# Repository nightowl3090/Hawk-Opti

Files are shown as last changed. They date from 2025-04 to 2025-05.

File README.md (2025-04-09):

## Hawk - Open Source Xbox Live Communicator - But Cheaper!

This project is an open source replacement of the [Microsoft Xbox Live Communicator](https://xbox.fandom.com/wiki/Xbox_LIVE_Headset) utilizing modern components and custom open-source firmware. 

This is a redesign intended to reduce the cost of production and assembly by moving vias off-pad and moving all components to the front side of the PCB. These simple changes reduce production and assembly costs by as much as 50%. 

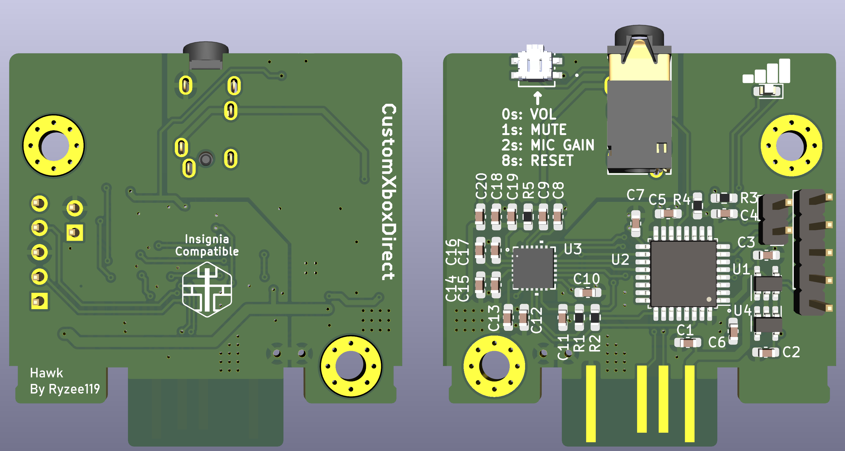
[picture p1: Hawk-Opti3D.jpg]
hawk!


It provides feature parity with the original communicator with the following differences:
* A 3.5mm TRRS jack is used to support more generic headsets. (Stereo headsets will output as mono.)
* The volume wheel is replaced with a button. Volume is indicated by LED brightness.

### Usage
* When installing Hawk into your controller, it must be installed in the slot closest to you.
* Press the button to increment the volume. Once maximum volume is reached, it will cycle back to zero.
* Hold the button for 1 second to mute and disable the microphone input (LED will flash at 1Hz).
* Hold the button 2 seconds to enter microphone gain adjustment mode (LED will flash at 4Hz).
* Volume and microphone gain adjustments will be saved internally. You can reset these to default by holding the button down for 8 seconds.

### Assembly
* **When ordering PCB thickness should be 1.2mm!**
* See [Kitspace](https://master.staging.kitspace.dev/Ryzee119/hawk) for BOM, PCB ordering and assembly information.
* See [KiCanvas](https://kicanvas.org/?github=https%3A%2F%2Fgithub.com%2FRyzee119%2Fhawk%2Ftree%2Fmaster%2Fhardware) for schematic view.
* See [Tracespace](https://tracespace.io/view/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) for Gerber view.

### Compilation
* Download and install [Visual Studio Code](https://code.visualstudio.com/).
* Install the [PlatformIO IDE](https://platformio.org/platformio-ide) plugin.
* In Visual Studio Code File > Open Folder... > hawk
* Hit build on the Platform IO toolbar (✓).

### Programming
* [Compile](https://github.com/Ryzee119/hawk?tab=readme-ov-file#compilation) or [Download](https://github.com/Ryzee119/hawk/releases) the pre-built firmware image.
* USB DFU. Connect an xbox controller to your PC, then hold the Hawk button down while inserting it into the controller to enter DFU mode. Your PC should detect this. you can then program with [STM32Cubeprogrammer](https://www.st.com/en/development-tools/stm32cubeprog.html)
* ST-Link interface (5 pin header available on PCB)

### FAQ
* What is the pinout of the headphone jack?
  * Hawk's headphone jack is wired as per [CTIA standard TRRS](https://upload.wikimedia.org/wikipedia/commons/e/ee/3.5mm_TRRS_phone_connector_with_CTIA_standard.png). There is another less common standard called OMTP. This will not work but adapters are available.
* It doesn't fit in my controller slot.
  * PCB should be manufactured with 1.2mm thickness. Most fabrication houses default to 1.6mm so be careful!
* Microphone is really quiet.
  * You can increase the microphone gain above default. Hold the Hawk button down for more than 2 seconds to enter gain adjustment mode. The LED will blink 4 times per second to show it is in the right mode then press the button to increase the gain. Hold for 1 second to exit. If this is still too quiet, you can modify the `MAX_MICROPHONE_GAIN` variable and recompile the code to bump it up even higher.
* Speaker is really quiet
  * Adjust the volume by pressing the button until the LED is at its maximum brightness. Unfortunately, it is already compiled to the maximum allowable by Hawk. If it is still too quiet, your headset's impedance may be too low.
* Does this work on modern controller adapters (ogx360, wingman etc)?
  * Not really, but kind of. To do this, you must connect a USB 1.1 compliant hub to the Xbox player port. Your controller then connects to port 1 of this hub and Hawk to port 2.
* LED just flashes constantly when connected
  * This means the main IC cannot communicate with the audio codec on Hawk. This is likely a soldering issue.
* `Error: Database: There's no active configuration for this device.` when programming.
  * Try an earlier revision of STM32CubeProgrammer. Users have reported some success with `v2.5.0`.

### Attribution
* [Board outline](https://github.com/Zeigren/OXC)
* [EEPROM emulation code](https://github.com/nimaltd/ee)

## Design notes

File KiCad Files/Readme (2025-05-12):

All necessary KiCad files for editing and export for production

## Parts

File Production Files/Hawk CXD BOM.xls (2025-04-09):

Item # | *Designator | *Qty | Manufacturer | *Mfg Part # | Description / Value | Cheapest Vendor | Vendor Part # | *Package/Footprint
1 | U1 | 1 | Microchip Technology | MIC5504-3.3YM5 | IC REG LINEAR 3.3V 300MA SOT23-5 | LCSC | C3021093 | SOT-23-5
2 | U2 | 1 | STMicroelectronics | STM32G431K6T6 | IC MCU 32BIT 32KB FLASH 32LQFP | Mouser | 511-STM32G431K6T6 | LQFP-32_7x7mm_P0.8mm
3 | U3 | 1 | Maxim Integrated | MAX9860ETG+T | IC CODEC MONO AUD 16BIT 24TQFN | LCSC | C516787 | 21-0139I_T2444-4_MXM
4 | U4 | 1 | Microchip Technology | MIC5504-1.8YM5 | IC REG LINEAR 1.8V 300MA SOT23-5 | Mouser | C626116『 』998-MIC5504-1.8YM5TR | SOT-23-5
5 | C1, C2, C3, C12, C20 | 5 | ANY | CAP CER 10uF 0603 | CAP CER 10uF 0603 | ANY | C19702『 』311-1448-1-ND | C_0603_1608Metric_Pad1.08x0.95mm_HandSolder
6 | C4, C5, C6, C7, C13 | 5 | ANY | CAP CER 100nF 0603 | CAP CER 100nF 0603 | ANY | C30926『 』311-1088-1-ND | C_0603_1608Metric_Pad1.08x0.95mm_HandSolder
7 | C8, C9, C10, C11, C14, C15, C16, C17, C18, C19 | 10 | ANY | CAP CER 1uF 0603 | CAP CER 1uF 0603 | ANY | C15849『 』311-1446-1-ND | C_0603_1608Metric_Pad1.08x0.95mm_HandSolder
8 | R1, R2, R4, R5 | 4 | ANY | RES SMD 1.5K OHM 1% 1/10W 0603 | RES SMD 1.5K OHM 1% 1/10W 0603 | ANY | C114668 | R_0603_1608Metric_Pad0.98x0.95mm_HandSolder
9 | R3 | 1 | ANY | RES SMD 150 OHM 1% 1/10W 0603 | RES SMD 150 OHM 1% 1/10W 0603 | ANY | C114608 | R_0603_1608Metric_Pad0.98x0.95mm_HandSolder
10 | D1 | 1 | ANY | LED 2V 20MA 0603 | LED 2V 20MA 0603 | ANY | C5123548 | LED_0603_1608Metric_Pad1.05x0.95mm_HandSolder
11 | J3 | 1 | Tensility International Corp | 54-00298 | CONN JACK TRRS 3.5MM | ANY | C707261 | 54-00298
12 | SW1 | 1 | Panasonic Electronic Components | EVQ-P7J01P | SWITCH TACTILE SPST-NO MOM | ANY | C2828254 | EVQ_P7_PAN

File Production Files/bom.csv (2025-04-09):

Designator | Footprint | Quantity | Value | LCSC Part #
C1, C12, C2, C20, C3 | 0603 | 5 | 10uF
C10, C11, C14, C15, C16, C17, C18, C19, C8, C9 | 0603 | 10 | 1uF
C13, C4, C5, C6, C7 | 0603 | 5 | 100nF
D1 | 0603 | 1 | LED
H1, H2 | MountingHole_3.2mm_M3_Pad_Via | 2 | MountingHole
J1 | PinHeader_1x02_P2.54mm_Vertical | 1 | UART2
J2 | PinHeader_1x05_P2.54mm_Vertical | 1 | SWD
J3 | 54-00298 | 1 | 54-00298
R1, R2, R4, R5 | 0603 | 4 | 1.5k
R3 | 0603 | 1 | 150
SW1 | EVQ_P7_PAN | 1 | EVQ-P7L01P
TP1 | TestPoint_Pad_1.0x1.0mm | 1 | USB_5V
TP2 | TestPoint_Pad_1.0x1.0mm | 1 | USB_GND
TP3 | TestPoint_Pad_1.0x1.0mm | 1 | USB_DM
TP4 | TestPoint_Pad_1.0x1.0mm | 1 | USB_DP
U1 | SOT-23-5 | 1 | MIC5504-3.3YM5
U2 | LQFP-32_7x7mm_P0.8mm | 1 | STM32G431K6Tx
U3 | 21-0139I_T2444-4_MXM | 1 | MAX9860ETG+T
U4 | SOT-23-5 | 1 | MIC5504-1.8YM5

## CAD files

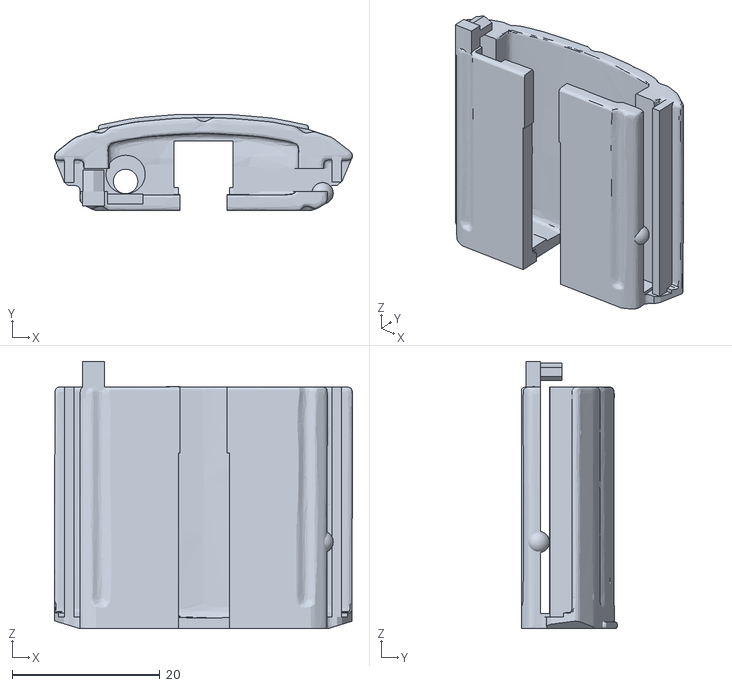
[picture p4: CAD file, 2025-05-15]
3D Prints/Hawk Opti Case.stl
40.4 x 13.0 x 36.2

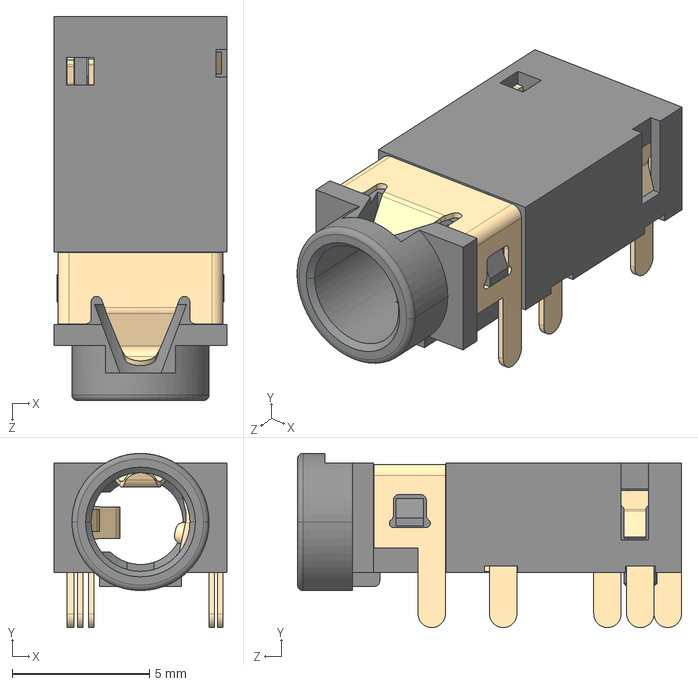
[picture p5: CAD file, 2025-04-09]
Parts/54-00298/54-00298.step
6.30 x 6.35 x 14.0 mm

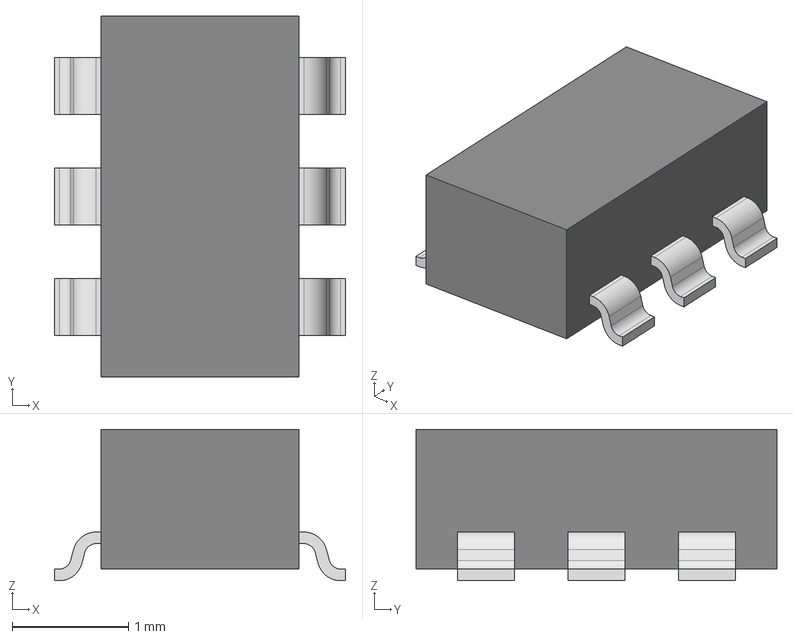
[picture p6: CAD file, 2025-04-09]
Parts/AP7312_1833W6_7/SOT26_DIO.step
2.50 x 3.10 x 1.30 mm

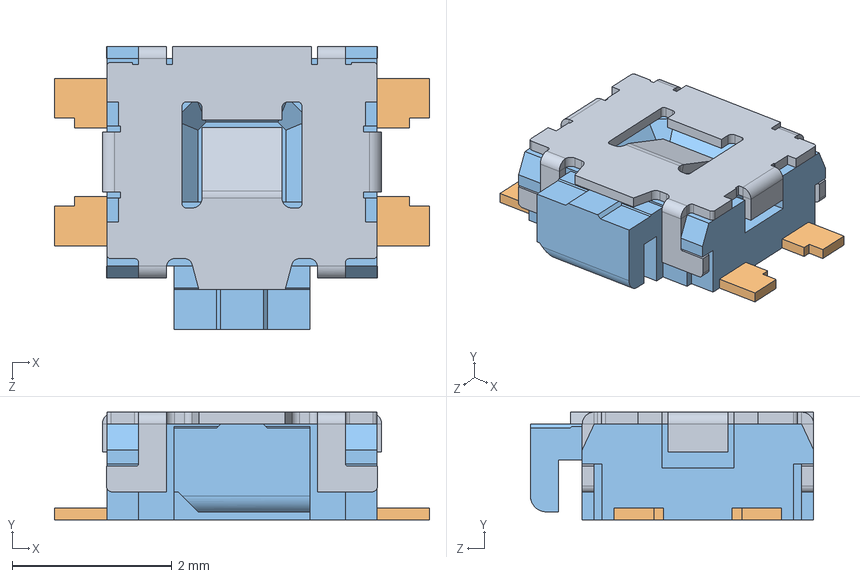
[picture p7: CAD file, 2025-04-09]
Parts/EVQ-P7L01P/EVQ-P7L01P.step
4.70 x 1.35 x 3.55 mm

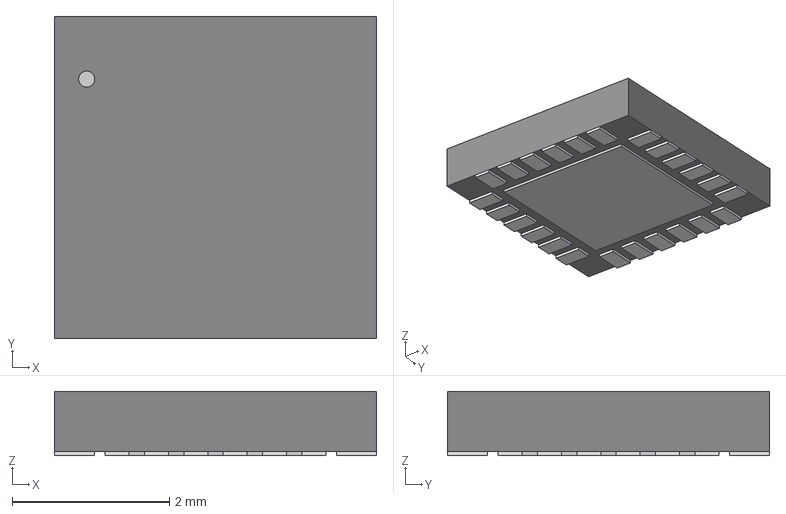
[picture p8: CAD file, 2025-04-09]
Parts/MAX9860ETG_T/21-0139I_T2444-4_MXM.step
4.09 x 4.09 x 0.815 mm

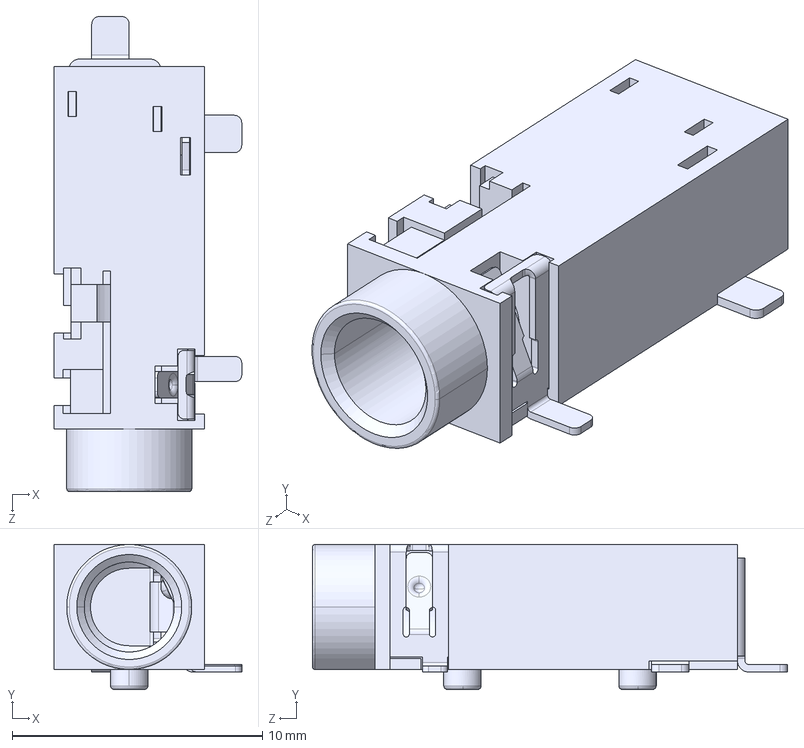
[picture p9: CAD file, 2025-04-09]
Parts/MJ_3523_SMT_TR/CUI_DEVICES_MJ-3523-SMT-TR.step
7.50 x 5.80 x 19.0 mm

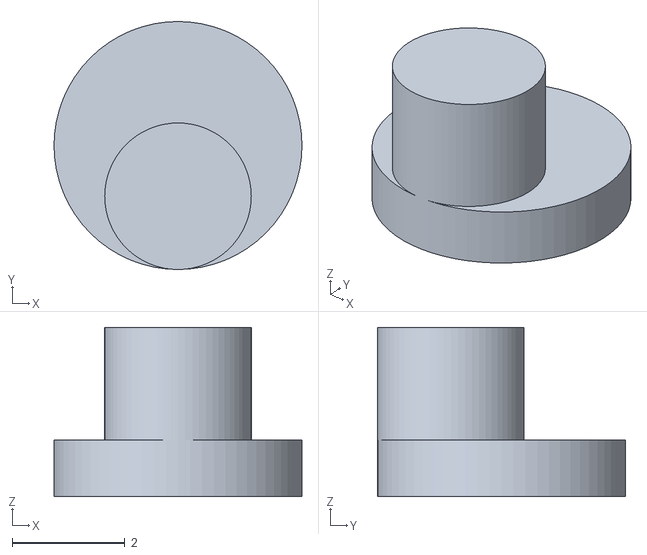
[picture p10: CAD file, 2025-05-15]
3D Prints/Hawk Opti Button.stl
4.40 x 4.40 x 3.00

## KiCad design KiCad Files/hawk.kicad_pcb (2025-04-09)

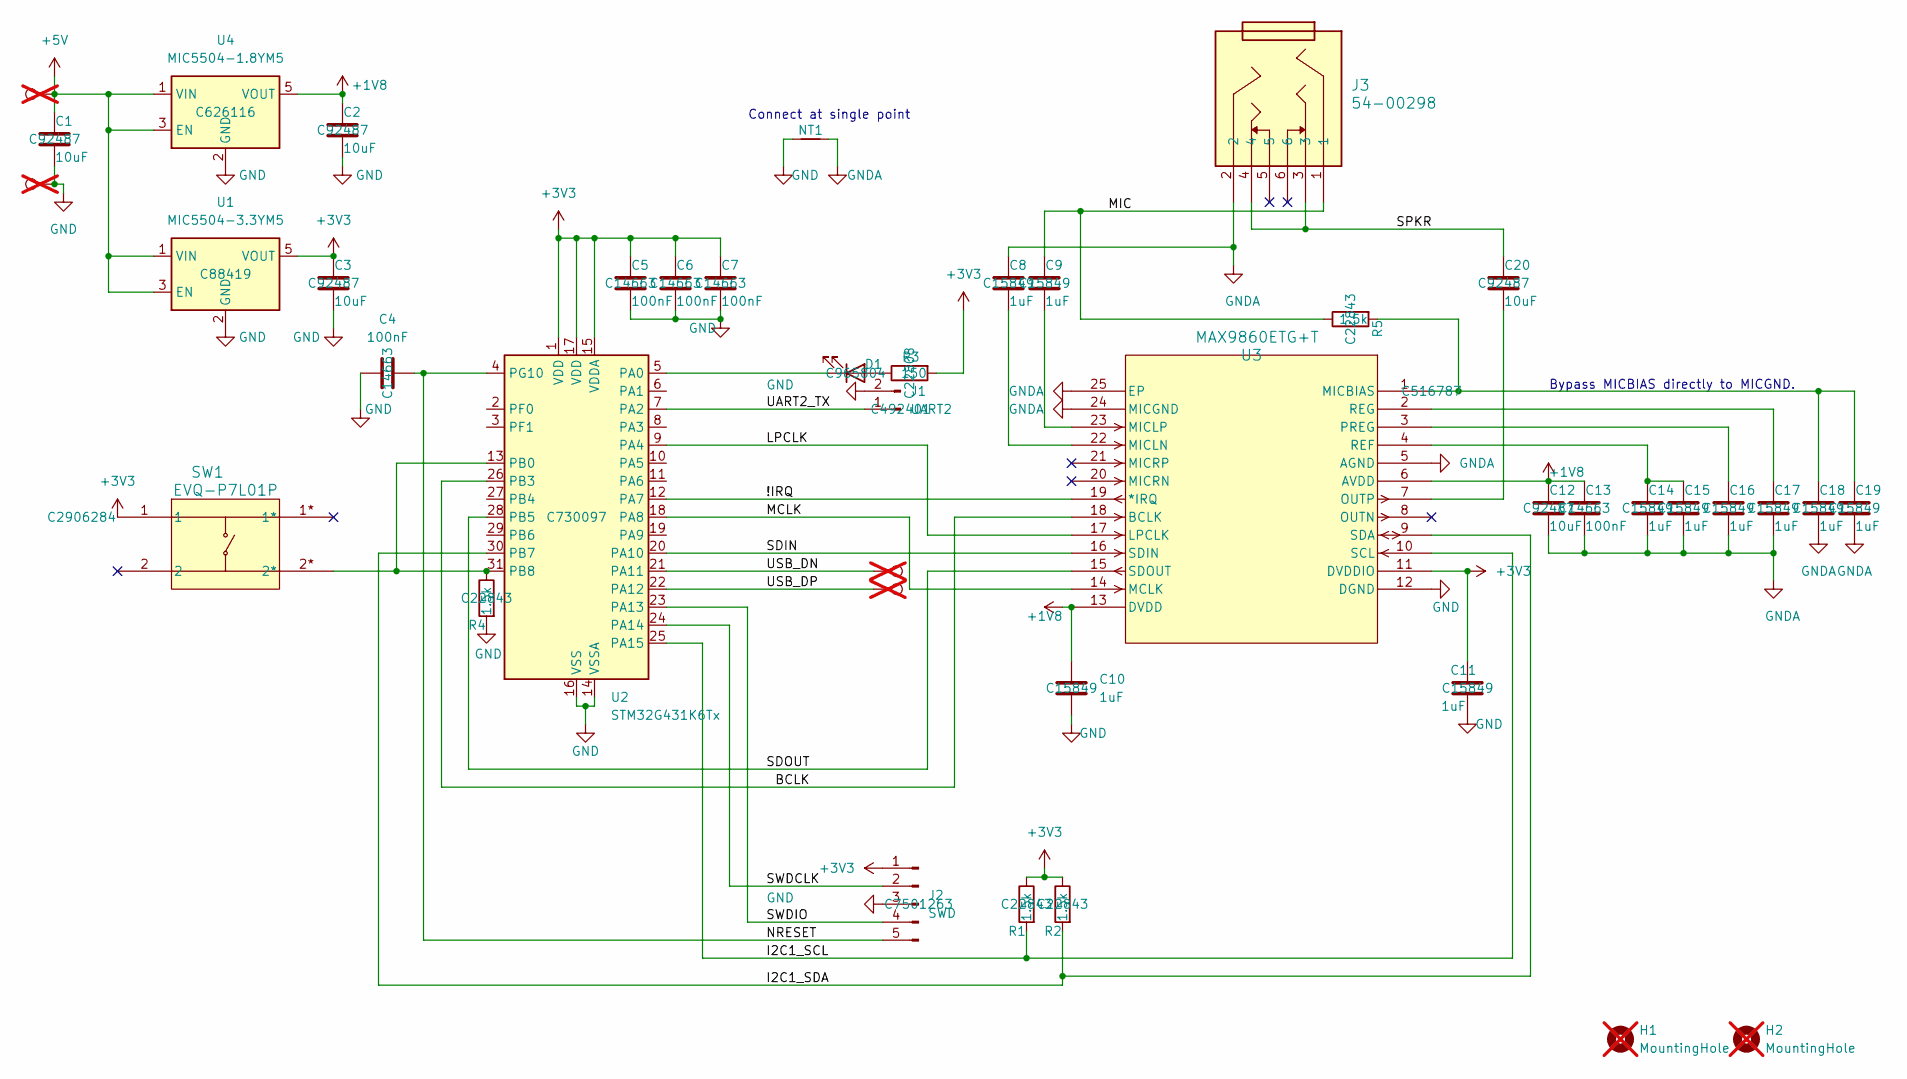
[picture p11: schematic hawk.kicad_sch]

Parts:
C1, C2, C3, C12, C20: 10uF; C_0603_1608Metric_Pad1.08x0.95mm_HandSolder; LCSC Part # C92487
C4, C5, C6, C7, C13: 100nF; C_0603_1608Metric_Pad1.08x0.95mm_HandSolder; LCSC Part # C14663
C8, C9, C10, C11, C14, C15, C16, C17, C18, C19: 1uF; C_0603_1608Metric_Pad1.08x0.95mm_HandSolder; LCSC Part # C15849
D1: LED; LED_0603_1608Metric_Pad1.05x0.95mm_HandSolder; LCSC Part # C965804
H1, H2: MountingHole; MountingHole_3.2mm_M3_Pad_Via; not fitted
J1: UART2; PinHeader_1x02_P2.54mm_Vertical; LCSC Part # C492401
J2: SWD; PinHeader_1x05_P2.54mm_Vertical; LCSC Part # C7501263
J3: 54-00298
NT1: NetTie_2; NetTie-2_THT_Pad1.0mm
R1, R2, R4, R5: 1.5k; R_0603_1608Metric_Pad0.98x0.95mm_HandSolder; LCSC Part # C22843
R3: 150; R_0603_1608Metric_Pad0.98x0.95mm_HandSolder; LCSC Part # C22808
SW1: EVQ-P7L01P; EVQ_P7_PAN; LCSC Part # C2906284
TP1: USB_5V; TestPoint_Pad_1.0x1.0mm; not fitted
TP2: USB_GND; TestPoint_Pad_1.0x1.0mm; not fitted
TP3: USB_DM; TestPoint_Pad_1.0x1.0mm; not fitted
TP4: USB_DP; TestPoint_Pad_1.0x1.0mm; not fitted
U1: MIC5504-3.3YM5; SOT-23-5; LCSC Part # C88419
U2: STM32G431K6Tx; LQFP-32_7x7mm_P0.8mm; LCSC Part # C730097
U3: MAX9860ETG+T; 21-0139I_T2444-4_MXM; LCSC Part # C516787
U4: MIC5504-1.8YM5; SOT-23-5; LCSC Part # C626116

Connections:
+1V8: C2.1, C10.1, C12.1, C13.1, U3.6 (AVDD), U3.13 (DVDD), U4.5 (VOUT)
+3V3: C3.1, C5.1, C6.1, C7.1, C11.1, J2.1, R1.1, R2.1, R3.2, SW1.1, U1.5 (VOUT), U2.1 (VDD), U2.15 (VDDA), U2.17 (VDD), U3.11 (DVDDIO)
+5V: C1.1, TP1.1, U1.1 (VIN), U1.3 (EN), U4.1 (VIN), U4.3 (EN)
/!IRQ: U2.12 (PA7), U3.19 (*IRQ)
/BCLK: U2.26 (PB3), U3.18 (BCLK)
/I2C1_SCL: R1.2, U2.25 (PA15), U3.10 (SCL)
/I2C1_SDA: R2.2, U2.30 (PB7), U3.9 (SDA)
/LPCLK: U2.9 (PA4), U3.17 (LPCLK)
/MCLK: U2.18 (PA8), U3.14 (MCLK)
/MIC: C9.1, J3.1, R5.1
/NRESET: C4.1, J2.5, U2.4 (PG10)
/SDIN: U2.20 (PA10), U3.16 (SDIN)
/SDOUT: U2.28 (PB5), U3.15 (SDOUT)
/SPKR: C20.1, J3.3, J3.4
/SWDCLK: J2.2, U2.24 (PA14)
/SWDIO: J2.4, U2.23 (PA13)
/UART2_TX: J1.1, U2.7 (PA2)
/USB_DN: TP3.1, U2.21 (PA11)
/USB_DP: TP4.1, U2.22 (PA12)
GND: C1.2, C2.2, C3.2, C4.2, C5.2, C6.2, C7.2, C10.2, C11.2, J1.2, J2.3, NT1.1, R4.2, TP2.1, U1.2 (GND), U2.14 (VSSA), U2.16 (VSS), U2.32 (VSS), U3.12 (DGND), U4.2 (GND)
GNDA: C8.1, C12.2, C13.2, C14.2, C15.2, C16.2, C17.2, C18.2, C19.2, J3.2, NT1.2, U3.5 (AGND), U3.24 (MICGND), U3.25 (EP)
unnamed: D1.2 (A), R3.1
unnamed: D1.1 (K), U2.5 (PA0)
unnamed: R4.1, SW1.2*, U2.13 (PB0), U2.31 (PB8)
unnamed: C18.1, C19.1, R5.2, U3.1 (MICBIAS)
unnamed: C8.2, U3.22 (MICLN)
unnamed: C9.2, U3.23 (MICLP)
unnamed: C20.2, U3.7 (OUTP)
unnamed: C16.1, U3.3 (PREG)
unnamed: C14.1, C15.1, U3.4 (REF)
unnamed: C17.1, U3.2 (REG)

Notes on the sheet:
Connect at single point
Bypass MICBIAS directly to MICGND.

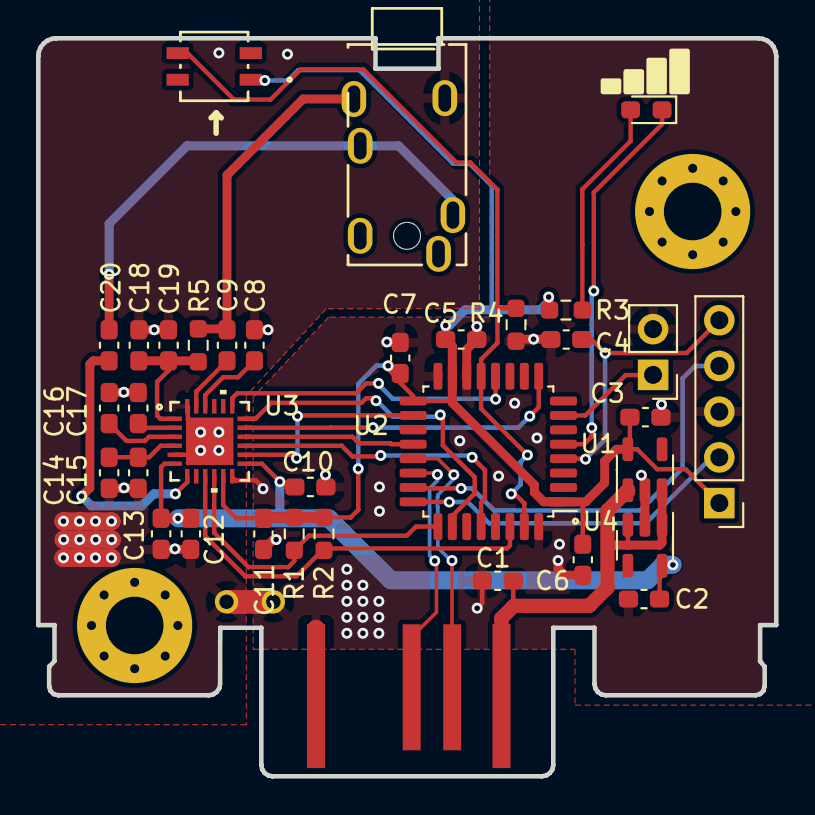
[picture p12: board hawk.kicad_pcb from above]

Board: 2 copper layers, 41.0 x 41.0 mm, 41 parts (0 on the bottom side), 31 nets.

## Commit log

2025-04-09 PCBWay BOM
    BOM optimized for ordering through PCBWay
    [Hawk CXD BOM.xls]
2025-05-12 Improved Shell and Button fit
    [Hawk Opti Button.stl, Hawk Opti Case .stl]
2025-05-12 Improved Shell Design and Button Fit
2025-05-12 Updated Final KiCad File
2025-05-12 Updated Footprints
2025-05-15 Improved Button Size and Fit
    [Hawk Opti Button.stl]
2025-05-15 Improved Shell Size and Fit
    [Hawk Opti Case.stl]
